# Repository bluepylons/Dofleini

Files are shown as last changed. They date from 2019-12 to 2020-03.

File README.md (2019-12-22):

# Dofleini Controller

Dofleini is an STM32 controller with a USB-C connector, for the [Boston keyboard](https://github.com/bluepylons/Boston). The idea was to move all SMT components into a separate daughterboard. It can also theoretically be used on any keyboard with separated F-keys. It has a total of 29 I/O pins.

The electrical schematic is copied off of the Acheron [Austin](https://github.com/Gondolindrim/Austin). 

The headers are on a 2.54mm (0.1") grid.

## Copyright Notice

This project is released under the Acheron Open-Hardware License V1.1.

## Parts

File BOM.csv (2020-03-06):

d | Value |  | Part No | Mouser Link
> C1, C10 | 10u | Capacitor_SMD:C_0805_2012Metric_Pad1.15x1.40mm_HandSolder | Taiyo Yuden LMK212ABJ106MG-T | https://www.mouser.com/ProductDetail/Taiyo-Yuden/LMK212ABJ106MG-T
> C3, C5, C7-C9 | 100n | Capacitor_SMD:C_0805_2012Metric_Pad1.15x1.40mm_HandSolder | Taiyo Yuden GMK212BJ104KGHT | https://www.mouser.com/ProductDetail/Taiyo-Yuden/GMK212BJ104KGHT
> C2, C4 | 4.7n | Capacitor_SMD:C_0805_2012Metric_Pad1.15x1.40mm_HandSolder | Kemet C0805C472K5RACTU | https://www.mouser.com/ProductDetail/KEMET/C0805C472K5RACTU?qs=sGAEpiMZZMs0AnBnWHyRQKp5FInkmPX80nEF8lJoBMw%3D
CRST1 | 10u | Capacitor_SMD:C_0805_2012Metric_Pad1.15x1.40mm_HandSolder | Taiyo Yuden LMK212ABJ106MG-T | https://www.mouser.com/ProductDetail/Taiyo-Yuden/LMK212ABJ106MG-T
CUSB1 | 4.7n | Capacitor_SMD:C_0805_2012Metric_Pad1.15x1.40mm_HandSolder | Kemet C0805C472K5RACTU | https://www.mouser.com/ProductDetail/KEMET/C0805C472K5RACTU?qs=sGAEpiMZZMs0AnBnWHyRQKp5FInkmPX80nEF8lJoBMw%3D
D1 | RB060M-60TR | acheronComponents:D_SOD-123 | RB060MM-60TFTR | https://www.mouser.com/ProductDetail/ROHM-Semiconductor/RB060MM-60TFTR
D2 | 1N4007 | Diode_THT:D_DO-41_SOD81_P10.16mm_Horizontal | EIC 1N4007 | https://www.taydaelectronics.com/1n4007-1a-1000v-rectifier-diode.html
D3 | 1N4148 | Diode_THT:D_DO-35_SOD27_P7.62mm_Horizontal |  | https://www.taydaelectronics.com/1n4148-switching-signal-diode.html
F1 | Polyfuse | Fuse:Fuse_1812_4532Metric_Pad1.30x3.40mm_HandSolder | Littelfuse 1812L075PR | https://www.mouser.com/ProductDetail/Littelfuse/1812L075PR
> H1, H2 | MountingHole | MountingHole:MountingHole_3.2mm_M3_ISO7380
J1 | Conn_ARM_JTAG_SWD_10 | Connector_PinHeader_2.54mm:PinHeader_1x10_P2.54mm_Vertical
J2 | Conn_01x09_Male | Connector_PinHeader_2.54mm:PinHeader_1x09_P2.54mm_Vertical
J3 | TYPE-C-31-M12_13 | acheronConnectors:TYPE-C-31-M-12 | HRO Type-C-31-M-12 | https://lcsc.com/product-detail/USB-Connectors_Korean-Hroparts-Elec-TYPE-C-31-M-12_C165948.html
J4 | Conn_01x22_Male | Connector_PinHeader_2.54mm:PinHeader_1x22_P2.54mm_Vertical |  | https://www.taydaelectronics.com/40-pin-2-54-mm-single-row-pin-header-strip.html
J5 | Conn_01x07_Male | Connector_PinHeader_2.54mm:PinHeader_1x07_P2.54mm_Vertical |  | https://www.taydaelectronics.com/40-pin-2-54-mm-single-row-pin-header-strip.html
Q1 | DTC123J | Package_TO_SOT_SMD:SOT-23 | Diodes Inc DDTC123JCA-7-F | https://www.mouser.com/ProductDetail/Diodes-Incorporated/DDTC123JCA-7-F
Q2 | AO4406AL | acheronComponents:SOIC-8
> R1, R2 | 100k | Resistor_SMD:R_0805_2012Metric_Pad1.15x1.40mm_HandSolder | Vishay CRCW0805100KJNEAC
R3 | 1M | Resistor_SMD:R_0805_2012Metric_Pad1.15x1.40mm_HandSolder | Vishay CRCW08051M00FKEAC
> R4, R5 | 5.1k | Resistor_SMD:R_0805_2012Metric_Pad1.15x1.40mm_HandSolder | Bourns CR0805-FX-5101ELF
R6 | 100 | Resistor_SMD:R_0805_2012Metric_Pad1.15x1.40mm_HandSolder | Vishay CRCW0805100RFKEAC
R7 | 10k | Resistor_SMD:R_0805_2012Metric_Pad1.15x1.40mm_HandSolder | Vishay CRCW080510K0FKEAC
U1 | STM32F072CBTx | Package_QFP:LQFP-48_7x7mm_P0.5mm | ST STM32F072CBT6 | https://www.mouser.com/ProductDetail/511-STM32F072CBT6
U2 | TLV1117-33 | Package_TO_SOT_SMD:SOT-223-3_TabPin2 | TI TLV1117-33IDCYR
U3 | USBLC6-2SC6 | Package_TO_SOT_SMD:SOT-23-6 | USBLC6-2SC6Y | https://www.mouser.com/ProductDetail/STMicroelectronics/USBLC6-2SC6Y

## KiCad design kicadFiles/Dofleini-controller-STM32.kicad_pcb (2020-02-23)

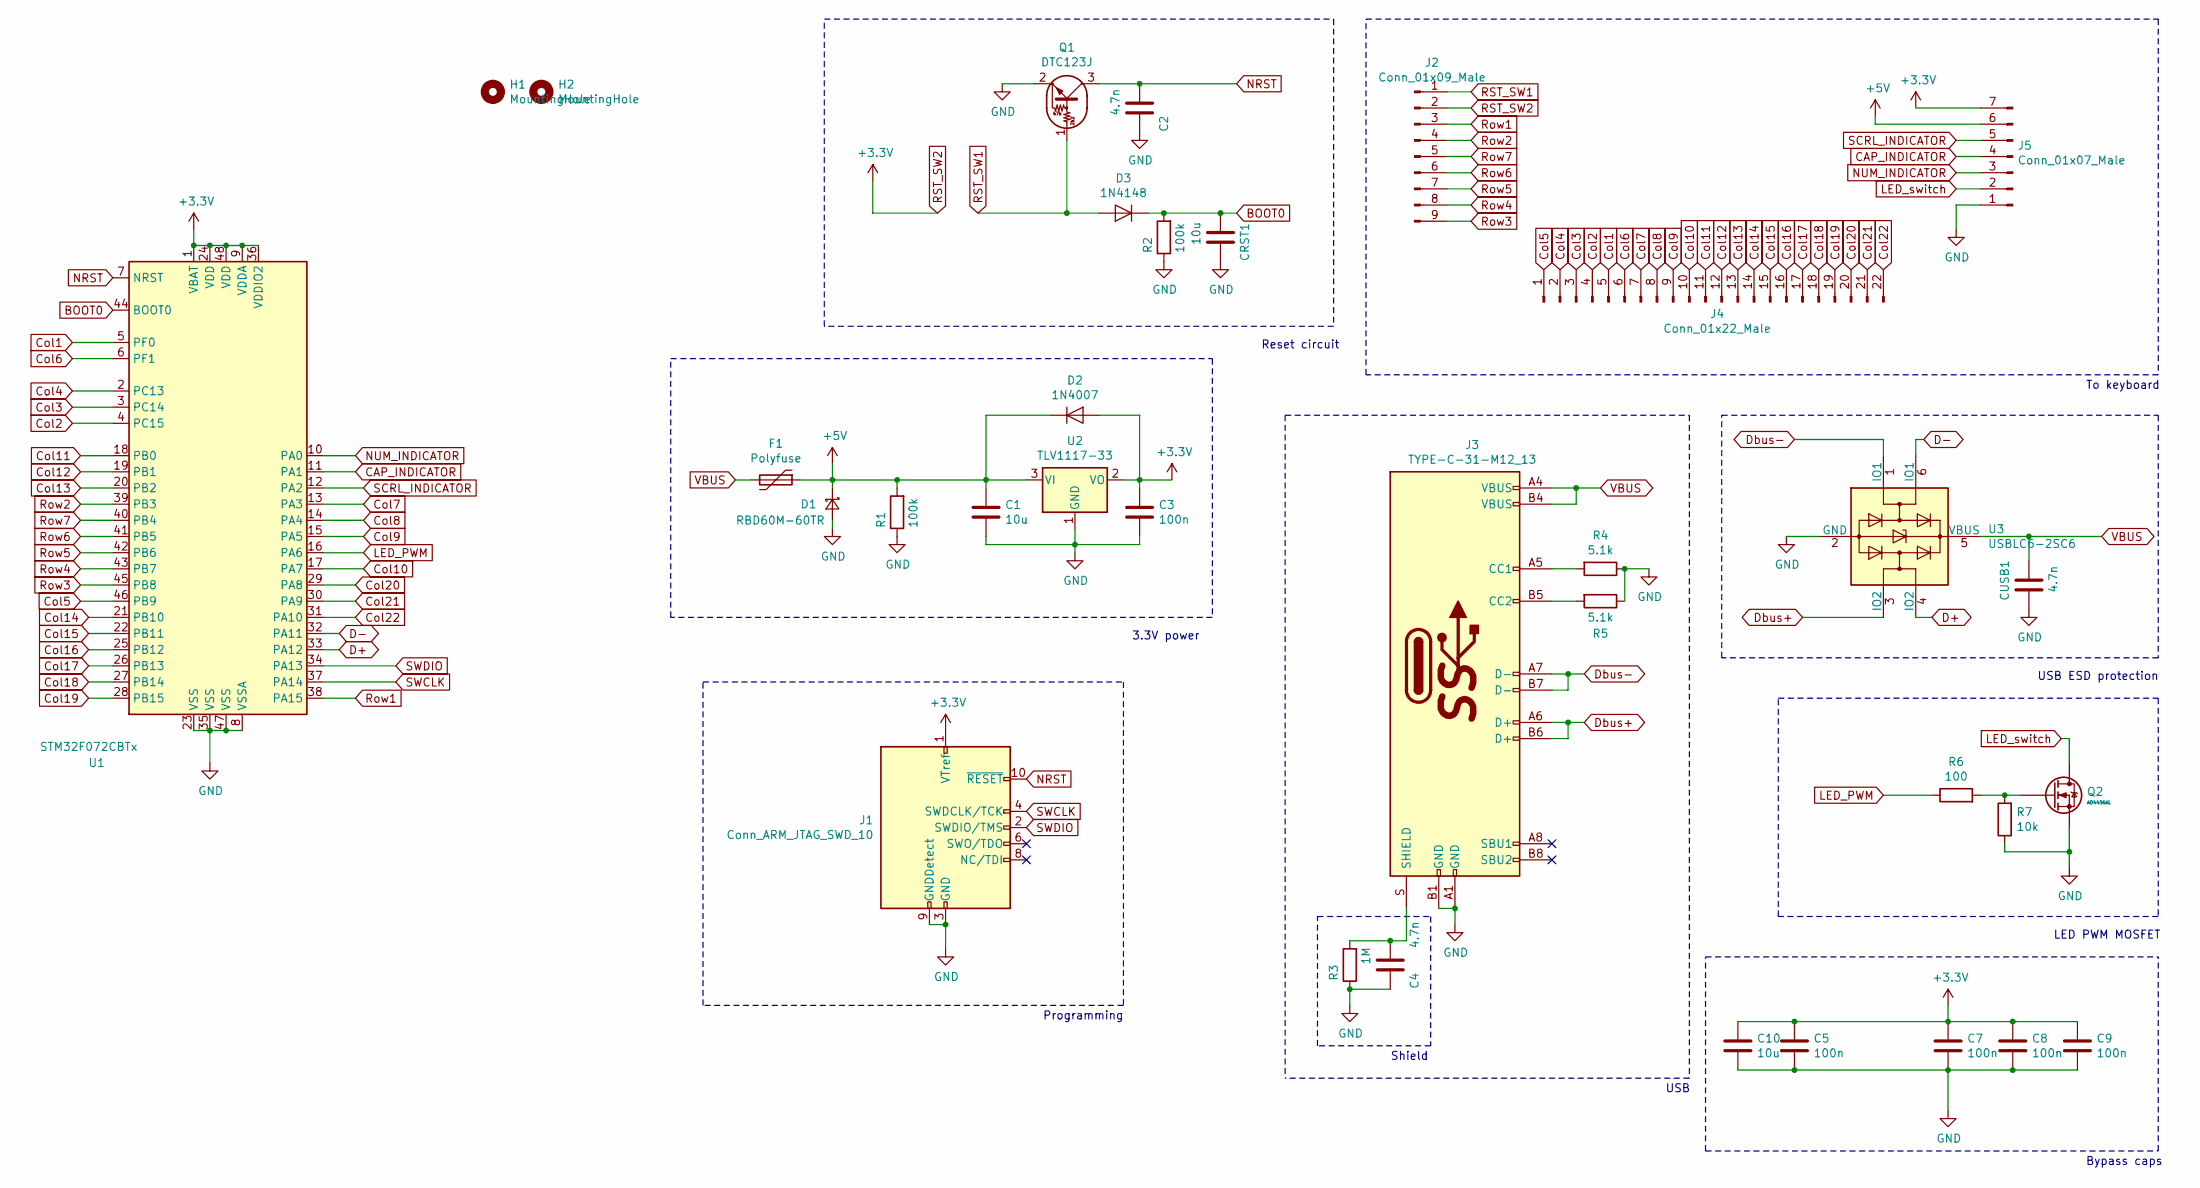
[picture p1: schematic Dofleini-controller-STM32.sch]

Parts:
C1, C10: 10u; C_0805_2012Metric_Pad1.15x1.40mm_HandSolder
C2, C4: 4.7n; C_0805_2012Metric_Pad1.15x1.40mm_HandSolder
C3, C5, C7, C8, C9: 100n; C_0805_2012Metric_Pad1.15x1.40mm_HandSolder
CRST1: 10u; C_0805_2012Metric_Pad1.15x1.40mm_HandSolder
CUSB1: 4.7n; C_0805_2012Metric_Pad1.15x1.40mm_HandSolder
D1: RBD60M-60TR; D_SOD-123
D2: 1N4007; D_DO-41_SOD81_P10.16mm_Horizontal
D3: 1N4148; D_DO-35_SOD27_P7.62mm_Horizontal
F1: Polyfuse; Fuse_1812_4532Metric_Pad1.30x3.40mm_HandSolder
H1, H2: MountingHole; MountingHole_3.2mm_M3_ISO7380
J1: Conn_ARM_JTAG_SWD_10; PinHeader_1x10_P2.54mm_Vertical
J2: Conn_01x09_Male; PinHeader_1x09_P2.54mm_Vertical
J3: TYPE-C-31-M12_13; TYPE-C-31-M-12
J4: Conn_01x22_Male; PinHeader_1x22_P2.54mm_Vertical
J5: Conn_01x07_Male; PinHeader_1x07_P2.54mm_Vertical
Q1: DTC123J; SOT-23
Q2: AO4406AL; SOIC-8
R1, R2: 100k; R_0805_2012Metric_Pad1.15x1.40mm_HandSolder
R3: 1M; R_0805_2012Metric_Pad1.15x1.40mm_HandSolder
R4, R5: 5.1k; R_0805_2012Metric_Pad1.15x1.40mm_HandSolder
R6: 100; R_0805_2012Metric_Pad1.15x1.40mm_HandSolder
R7: 10k; R_0805_2012Metric_Pad1.15x1.40mm_HandSolder
U1: STM32F072CBTx; LQFP-48_7x7mm_P0.5mm
U2: TLV1117-33; SOT-223-3_TabPin2
U3: USBLC6-2SC6; SOT-23-6

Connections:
+5V: C1.1, D1.1 (K), D2.1 (K), F1.1, J5.6, R1.2, U2.3 (VI)
BOOT0: CRST1.1, D3.1 (K), R2.2, U1.44 (BOOT0)
CAP_INDICATOR: J5.4, U1.11 (PA1)
Col1: J4.5, U1.5 (PF0)
Col2: J4.4, U1.4 (PC15)
Col3: J4.3, U1.3 (PC14)
Col4: J4.2, U1.2 (PC13)
Col5: J4.1, U1.46 (PB9)
Col6: J4.6, U1.6 (PF1)
Col7: J4.7, U1.13 (PA3)
Col8: J4.8, U1.14 (PA4)
Col9: J4.9, U1.15 (PA5)
Col10: J4.10, U1.17 (PA7)
Col11: J4.11, U1.18 (PB0)
Col12: J4.12, U1.19 (PB1)
Col13: J4.13, U1.20 (PB2)
Col14: J4.14, U1.21 (PB10)
Col15: J4.15, U1.22 (PB11)
Col16: J4.16, U1.25 (PB12)
Col17: J4.17, U1.26 (PB13)
Col18: J4.18, U1.27 (PB14)
Col19: J4.19, U1.28 (PB15)
Col20: J4.20, U1.29 (PA8)
Col21: J4.21, U1.30 (PA9)
Col22: J4.22, U1.31 (PA10)
D+: U1.33 (PA12), U3.4 (IO2)
D-: U1.32 (PA11), U3.6 (IO1)
Dbus+: J3.A6 (D+), J3.B6 (D+), U3.3 (IO2)
Dbus-: J3.A7 (D-), J3.B7 (D-), U3.1 (IO1)
GND: C1.2, C2.2, C3.2, C4.2, C5.2, C7.2, C8.2, C9.2, C10.2, CRST1.2, CUSB1.2, D1.2 (A), J1.3 (GND), J1.5 (GND), J1.9 (GNDDetect), J3.A1 (GND), J3.B1 (GND), J5.1, Q1.2 (E), Q2.1, Q2.2, Q2.3, R1.1, R2.1, R3.1, R4.1, R5.1, R7.1, U1.8 (VSSA), U1.23 (VSS), U1.35 (VSS), U1.47 (VSS), U2.1 (GND), U3.2 (GND)
LED_PWM: R6.1, U1.16 (PA6)
LED_switch: J5.2, Q2.5 (D), Q2.6, Q2.7, Q2.8
NRST: C2.1, J1.10 (~RESET~), Q1.3 (C), U1.7 (NRST)
NUM_INDICATOR: J5.3, U1.10 (PA0)
unnamed: C4.1, J3.S (SHIELD), R3.2
unnamed: J3.A5 (CC1), R4.2
unnamed: J3.B5 (CC2), R5.2
unnamed: Q2.4 (G), R6.2, R7.2
RST_SW1: D3.2 (A), J2.1, Q1.1 (B)
RST_SW2: C3.1, C5.1, C7.1, C8.1, C9.1, C10.1, D2.2 (A), J1.1 (VTref), J2.2, J5.7, U1.1 (VBAT), U1.9 (VDDA), U1.24 (VDD), U1.36 (VDDIO2), U1.48 (VDD), U2.2 (VO)
Row1: J2.3, U1.38 (PA15)
Row2: J2.4, U1.39 (PB3)
Row3: J2.9, U1.45 (PB8)
Row4: J2.8, U1.43 (PB7)
Row5: J2.7, U1.42 (PB6)
Row6: J2.6, U1.41 (PB5)
Row7: J2.5, U1.40 (PB4)
SCRL_INDICATOR: J5.5, U1.12 (PA2)
SWCLK: J1.4 (SWDCLK/TCK), U1.37 (PA14)
SWDIO: J1.2 (SWDIO/TMS), U1.34 (PA13)
VBUS: CUSB1.1, F1.2, J3.A4 (VBUS), J3.B4 (VBUS), U3.5 (VBUS)

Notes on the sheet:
Shield
Bypass caps
USB ESD protection
USB
Reset circuit
3.3V power
To keyboard
LED PWM MOSFET
Programming

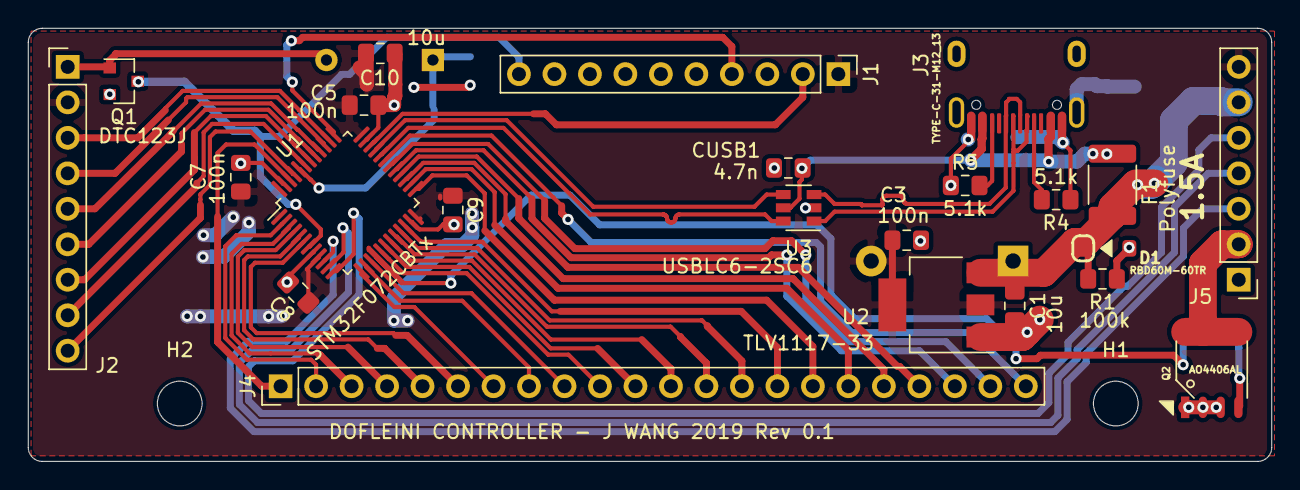
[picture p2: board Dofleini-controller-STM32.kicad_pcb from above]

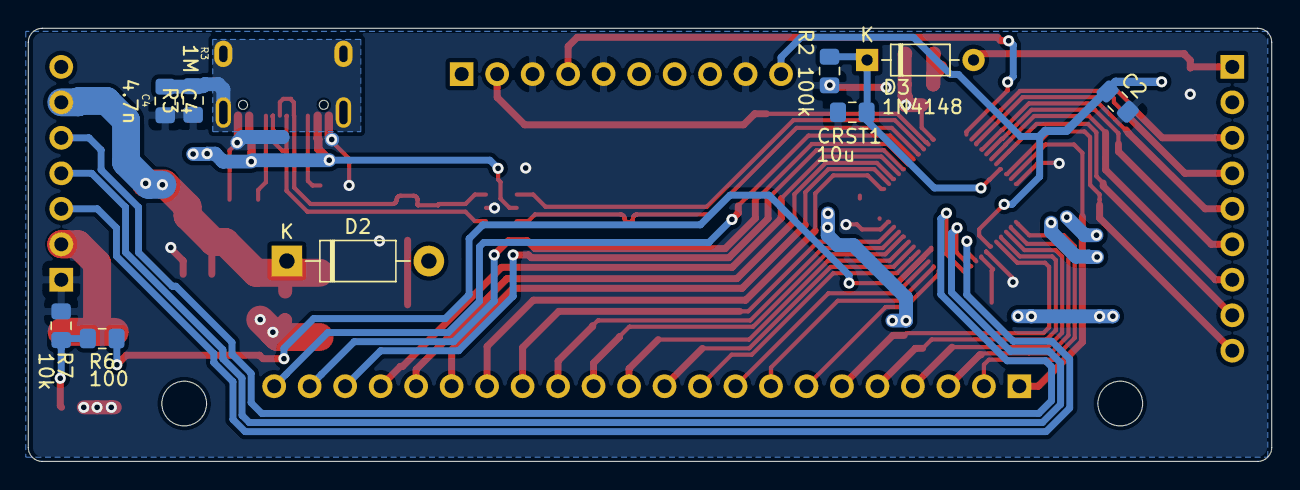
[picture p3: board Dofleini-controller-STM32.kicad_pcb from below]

Board: 2 copper layers, 89.0 x 31.0 mm, 34 parts (9 on the bottom side), 51 nets.

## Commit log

2020-02-23 Added mounting holes
    [Dofleini-controller-STM32-B_Cu.gbr, Dofleini-controller-STM32-B_Mask.gbr, Dofleini-controller-STM32-B_Paste.gbr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]
2020-03-02 Added BOM
    [BOM.csv, Dofleini-controller-STM32.sch]
2020-03-06 Made BOM
    [BOM.csv]
